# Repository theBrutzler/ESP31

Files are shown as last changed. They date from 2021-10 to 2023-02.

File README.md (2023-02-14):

# ESP31
ESP32 -> ESP01

I created a board, that could fit an ESP32 on a ESP01 standard pinout. The default ESP01 programer is still working
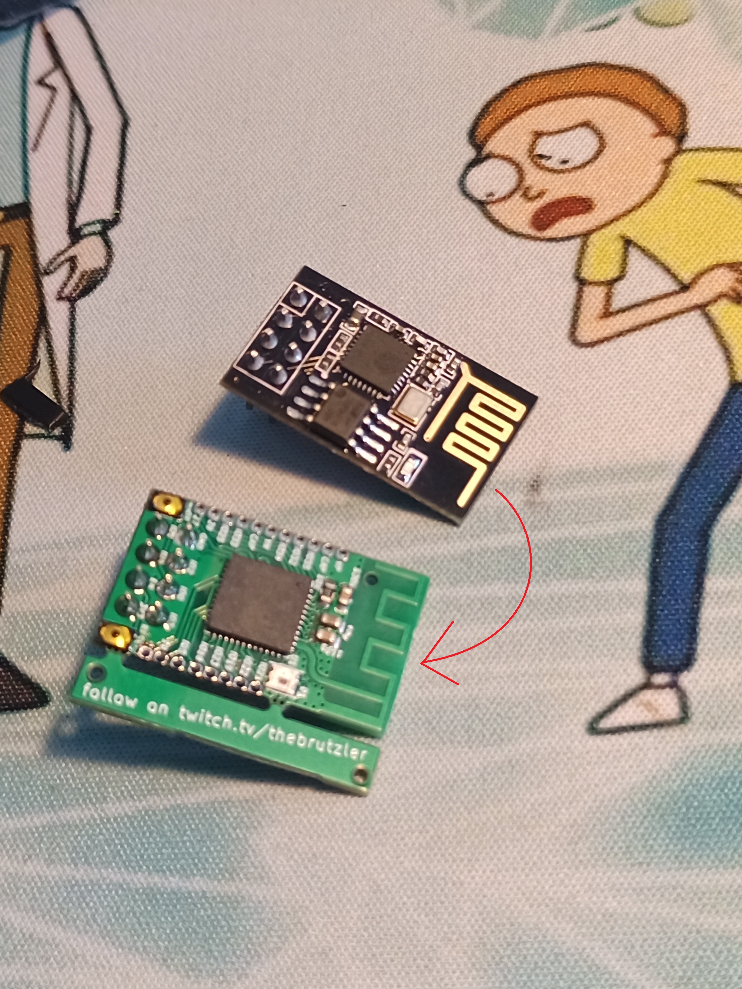
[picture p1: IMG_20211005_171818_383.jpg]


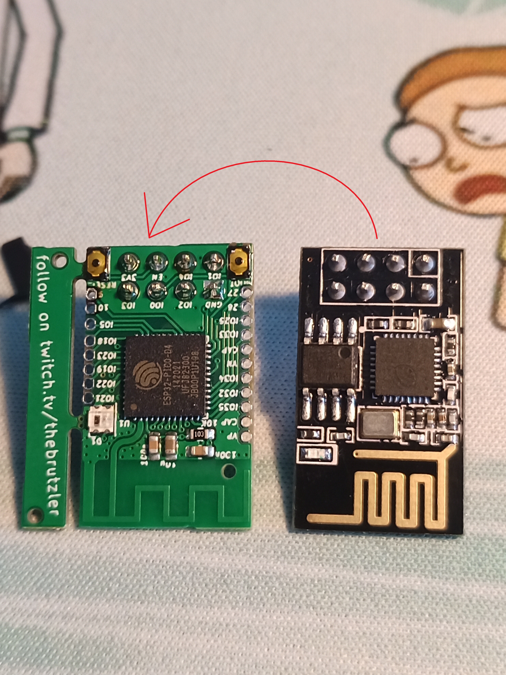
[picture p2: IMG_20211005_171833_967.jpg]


This is the NEW 5V Version but first open the RTFM.png ;)
with V4 default is 5V operation. Works fine with 3.3 too. If u have problems make the RTFM.png

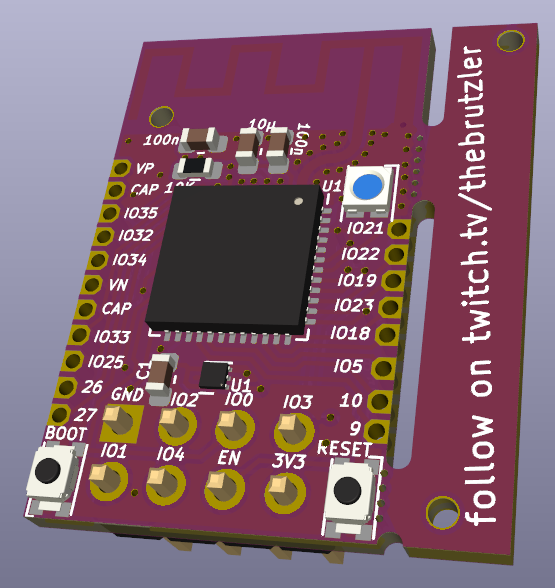
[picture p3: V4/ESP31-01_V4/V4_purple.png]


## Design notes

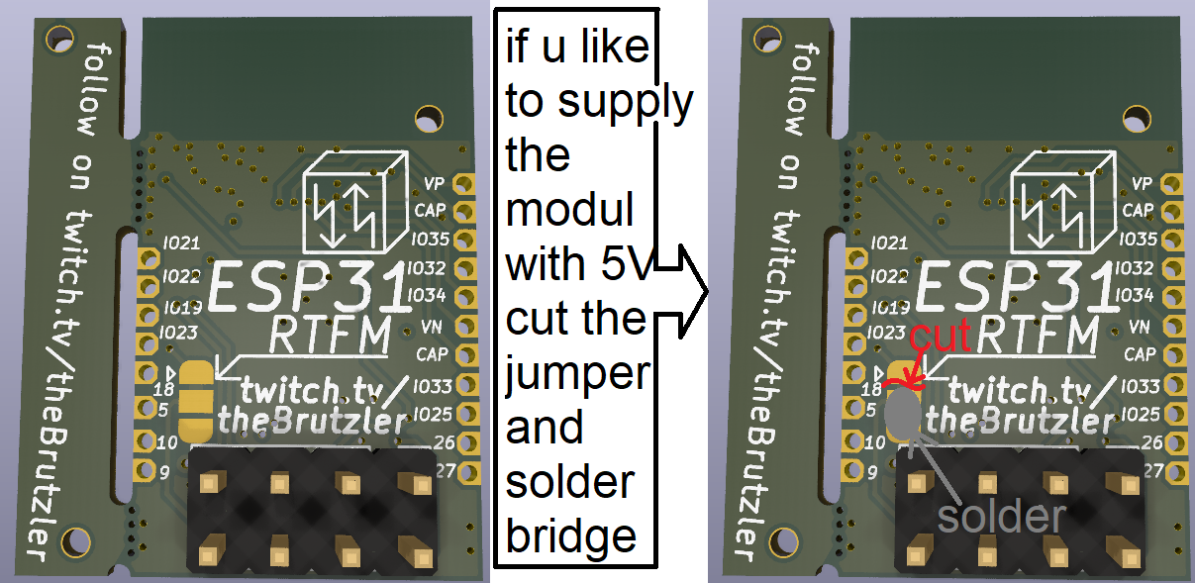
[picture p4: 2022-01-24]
RTFM.png

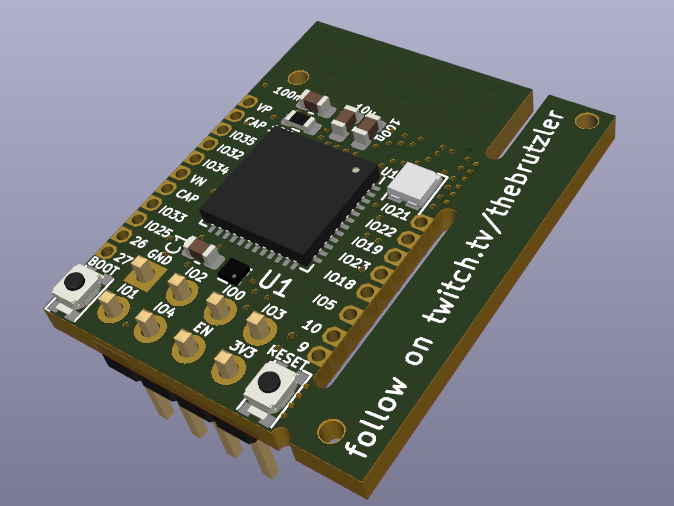
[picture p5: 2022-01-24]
V3_3D_Model.PNG

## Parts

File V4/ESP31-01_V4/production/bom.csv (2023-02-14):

Designator | Footprint | Quantity | Value | LCSC Part #
_12, _11, _10, _9, _8, _7, _6, _5, _4, _3, _2, |  | 12
AE1 | Texas_SWRA117D_2.4GHz_Left | 1 | Antenna_Shield
C1 | 0603 | 1 | 100n | C282519
C2 | 0603 | 1 | 100n | C282519
C3 | 0603 | 1 | 10µ | C85713
C4 | 0603 | 1 | 100n | C282519
D1 | LED_Cree-PLCC4_2x2mm_CW | 1 | WS2812B_Geaendertes_Symbol | C965556
J1, J10, J11, J12, J13, J14, J15, J16, J17, J18, J19, J2, J3, J4, J5, J6, J7, J8_2, J8, J9_2, J9 | CON_1x01 | 21 | Conn_01x01
J20 | PinHeader_2x04_P2.54mm_Vertical | 1 | Conn_02x04_Odd_Even
JP1, JP2 | SolderJumper-3_P1.3mm_Bridged12_RoundedPad1.0x1.5mm | 2 | SolderJumper_3_Bridged12
R1 | 0603 | 1 | 10K | C73809
SM3 | Symbol_kurzschlussblog | 1 | SYM_Arrow45_Tiny
SW1, SW2 | microswitch | 2 | SW_Push | C482003
U1 | DFN-6-1EP_1.2x1.2mm_P0.4mm_EP0.3x0.94mm_PullBack | 1 | MIC5528 | C622490
U2 | QFN-48-1EP_7x7mm_P0.5mm_EP5.3x5.3mm | 1 | ESP32-PICO-D4 | C193707

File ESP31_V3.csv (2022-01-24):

Comment | Designator | Footprint | LCSC
Antenna_Shield | AE1 | RF_Antenna:Texas_SWRA117D_2.4GHz_Left
100n | C1,C2,C4 | Capacitor_SMD:C_0603_1608Metric | C282519
10µ | C3 | Capacitor_SMD:C_0603_1608Metric | C85713
WS2812B_Geaendertes_Symbol | D1 | LED_SMD:LED_Cree-PLCC4_2x2mm_CW | C965556
Conn_01x01 | J1,J2,J3,J4,J5,J6,J7,J8,J9,J10,J11,J12,J13,J14,J15,J16,J17,J18,J19 | Eigene:CON_1x01
Conn_02x04_Odd_Even | J20 | Connector_PinHeader_2.54mm:PinHeader_2x04_P2.54mm_Vertical
SolderJumper_3_Bridged12 | JP1 | Jumper:SolderJumper-3_P1.3mm_Bridged12_RoundedPad1.0x1.5mm
10K | R1 | Resistor_SMD:R_0603_1608Metric | C73809
SW_Push | SW1,SW2 | TheBrutzlers_Lib:microswitch | C100056
WL2810 | U1 | Package_DFN_QFN:UDFN-4-1EP_1x1mm_P0.65mm_EP0.48x0.48mm | C506118
ESP32-PICO-D4 | U2 | Package_DFN_QFN:QFN-48-1EP_7x7mm_P0.5mm_EP5.3x5.3mm

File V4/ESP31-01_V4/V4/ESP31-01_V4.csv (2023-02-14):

ID | Bezeichner | Gehäuse | Stückzahl | Bezeichnung | Anbieter und Referenz
1 | J8,J5,J10,J7,J18,J9,J6,J12,J19,J13,J15,J17,J14,J8,J3,J4,J11,J9,J1,J16,J2 | CON_1x01 | 21 | Conn_01x01
2 | U1 | DFN-6-1EP_1.2x1.2mm_P0.4mm_EP0.3x0.94mm_PullBack | 1 | MIC5528
3 | C2,C1,C4 | C_0603_1608Metric | 3 | 100n
4 | REF** | jlc_tooling | 1 | jlc_tooling
5 | REF** | mousebite | 1 | mousebite
6 | ,,,,,,,,,,, |  | 12
7 | C3 | C_0603_1608Metric | 1 | 10µ
8 | U2 | QFN-48-1EP_7x7mm_P0.5mm_EP5.3x5.3mm | 1 | ESP32-PICO-D4
9 | AE1 | Texas_SWRA117D_2.4GHz_Left | 1 | Antenna_Shield
10 | R1 | R_0603_1608Metric | 1 | 10K
11 | SW1,SW2 | microswitch | 2 | SW_Push
12 | D1 | LED_Cree-PLCC4_2x2mm_CW | 1 | WS2812B_Geaendertes_Symbol
13 | JP2,JP1 | SolderJumper-3_P1.3mm_Bridged12_RoundedPad1.0x1.5mm | 2 | SolderJumper_3_Bridged12
14 | SM3 | Symbol_kurzschlussblog | 1 | SYM_Arrow45_Tiny
15 | J20 | PinHeader_2x04_P2.54mm_Vertical | 1 | Conn_02x04_Odd_Even

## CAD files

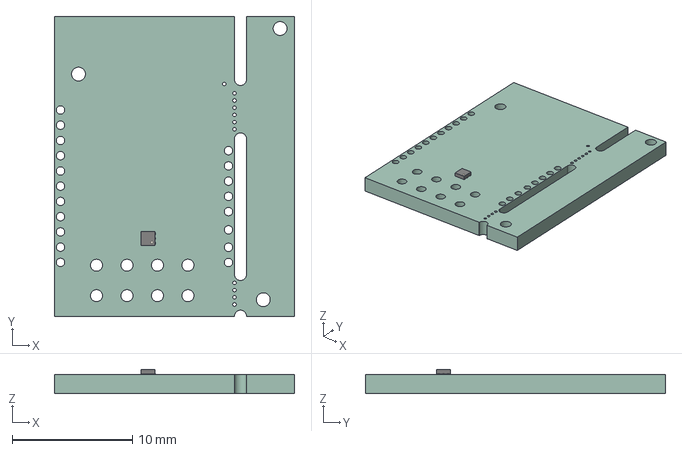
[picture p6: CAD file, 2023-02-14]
V4/ESP31-01_V4/ESP31-01_V4.step
20.0 x 25.0 x 2.04 mm
ESP31_V3 PCB

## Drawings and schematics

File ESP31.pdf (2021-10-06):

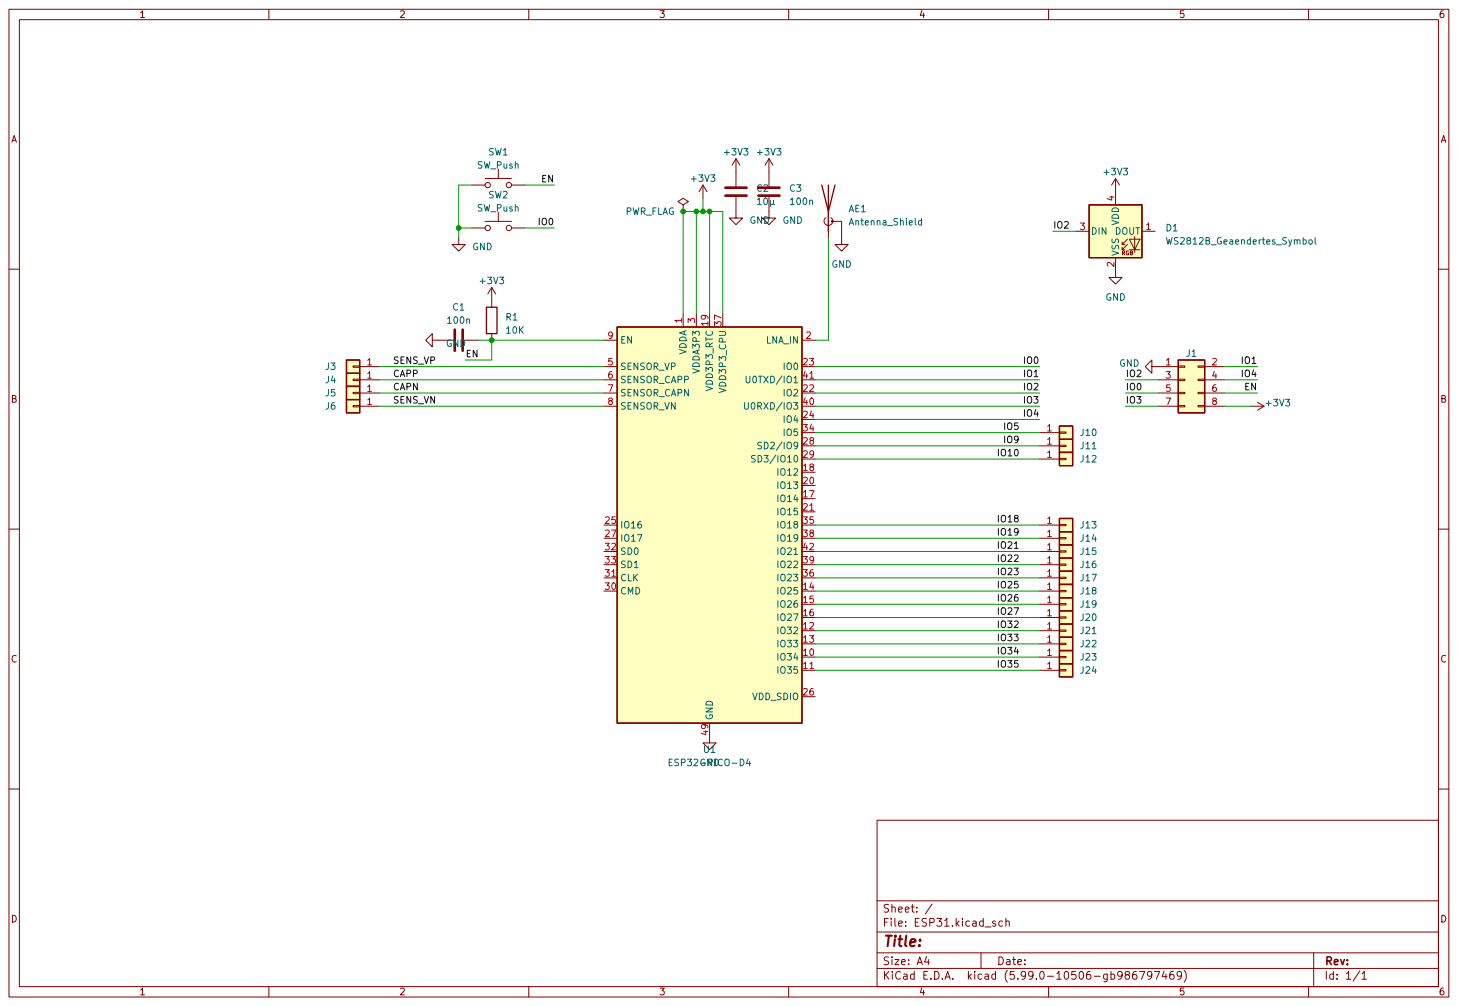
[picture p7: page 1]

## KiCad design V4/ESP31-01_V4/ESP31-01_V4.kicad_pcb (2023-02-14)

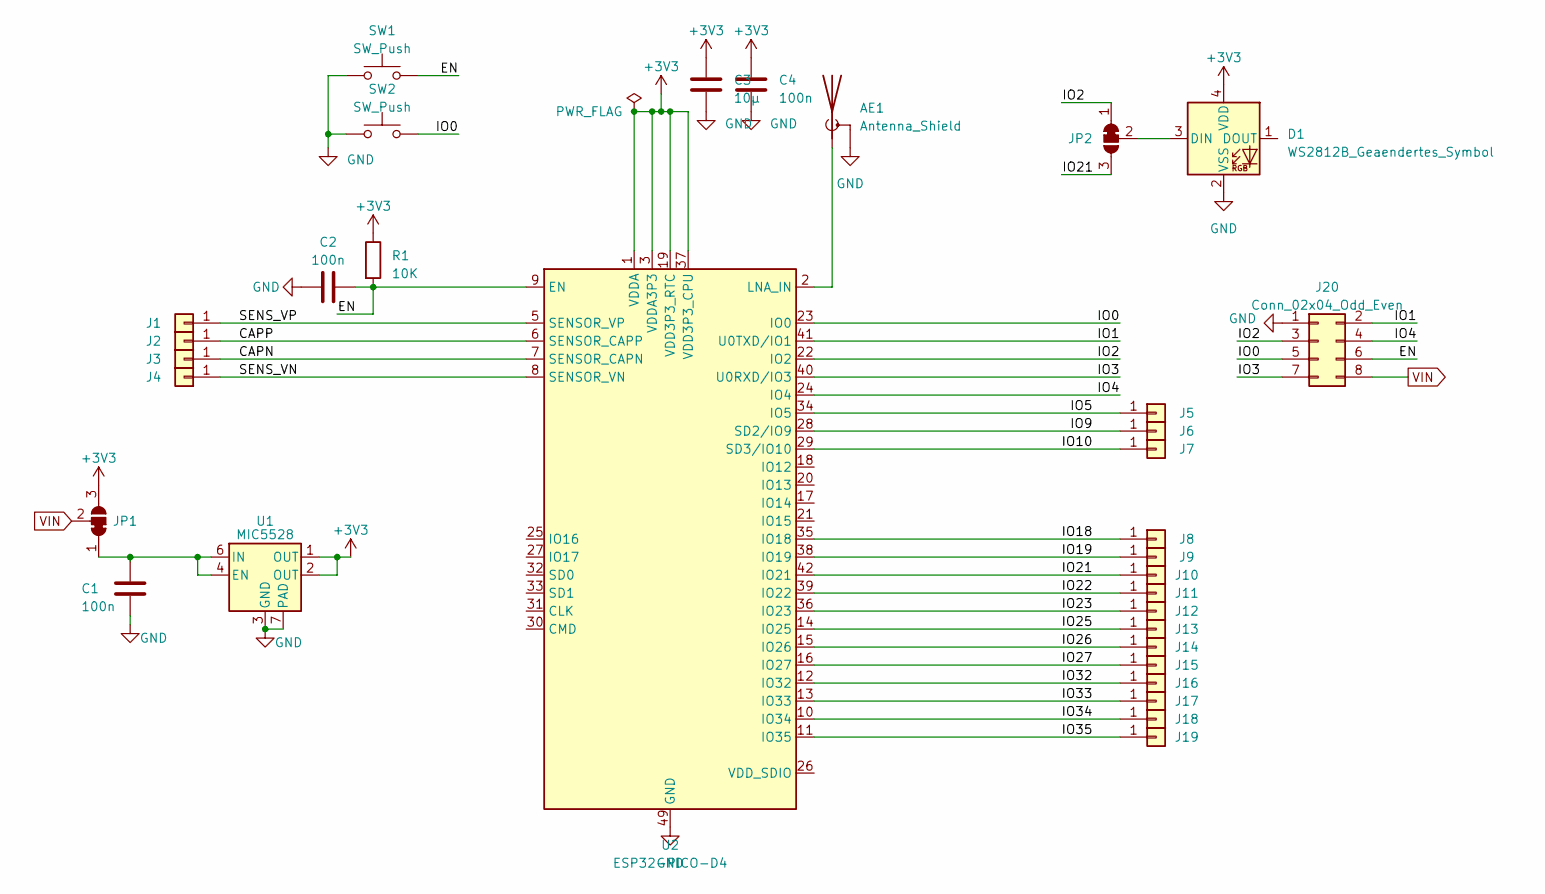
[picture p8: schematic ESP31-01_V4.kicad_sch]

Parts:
AE1: Antenna_Shield; Texas_SWRA117D_2.4GHz_Left
C1, C2, C4: 100n; C_0603_1608Metric; LCSC C282519
C3: 10µ; C_0603_1608Metric; LCSC C85713
D1: WS2812B_Geaendertes_Symbol; LED_Cree-PLCC4_2x2mm_CW; LCSC C965556
J1, J2, J3, J4, J5, J6, J7, J8, J9, J10, J11, J12, J13, J14, J15, J16, J17, J18, J19: Conn_01x01; CON_1x01
J20: Conn_02x04_Odd_Even; PinHeader_2x04_P2.54mm_Vertical
JP1, JP2: SolderJumper_3_Bridged12; SolderJumper-3_P1.3mm_Bridged12_RoundedPad1.0x1.5mm
R1: 10K; R_0603_1608Metric; LCSC C73809
SW1: SW_Push; microswitch; LCSC C482003
SW2: SW_Push; microswitch; LCSC C100056
U1: MIC5528; DFN-6-1EP_1.2x1.2mm_P0.4mm_EP0.3x0.94mm_PullBack; LCSC C622490
U2: ESP32-PICO-D4; QFN-48-1EP_7x7mm_P0.5mm_EP5.3x5.3mm; LCSC C193707

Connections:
+3V3: C3.2, C4.2, D1.4 (VDD), JP1.3 (B), R1.1, U1.1 (OUT), U1.2 (OUT), U2.1 (VDDA), U2.3 (VDDA3P3), U2.4 (VDDA3P3), U2.19 (VDD3P3_RTC), U2.37 (VDD3P3_CPU), U2.43 (VDDA), U2.46 (VDDA)
/CAPN: J3.1, U2.7 (SENSOR_CAPN)
/CAPP: J2.1, U2.6 (SENSOR_CAPP)
/EN: C2.1, J20.6, R1.2, SW1.2, U2.9 (EN)
/IO0: J20.5, SW2.2, U2.23 (IO0)
/IO1: J20.2, U2.41 (U0TXD/IO1)
/IO2: J20.3, JP2.1 (A), U2.22 (IO2)
/IO3: J20.7, U2.40 (U0RXD/IO3)
/IO4: J20.4, U2.24 (IO4)
/IO5: J5.1, U2.34 (IO5)
/IO9: J6.1, U2.28 (SD2/IO9)
/IO10: J7.1, U2.29 (SD3/IO10)
/IO18: J8.1, U2.35 (IO18); also elsewhere on the board
/IO19: J9.1, U2.38 (IO19)
/IO21: J10.1, JP2.3 (B), U2.42 (IO21)
/IO22: J11.1, U2.39 (IO22)
/IO23: J12.1, U2.36 (IO23)
/IO25: J13.1, U2.14 (IO25)
/IO26: J14.1, U2.15 (IO26)
/IO27: J15.1, U2.16 (IO27)
/IO32: J16.1, U2.12 (IO32)
/IO33: J17.1, U2.13 (IO33)
/IO34: J18.1, U2.10 (IO34)
/IO35: J19.1, U2.11 (IO35)
/SENS_VN: J4.1, U2.8 (SENSOR_VN)
/SENS_VP: J1.1, U2.5 (SENSOR_VP)
GND: AE1.2 (Shield), C1.1, C2.2, C3.1, C4.1, D1.2 (VSS), J20.1, SW1.1, SW2.1, U1.3 (GND), U1.7 (PAD), U2.49 (GND)
unnamed: AE1.1 (A), U2.2 (LNA_IN)
unnamed: C1.2, JP1.1 (A), U1.4 (EN), U1.6 (IN)
unnamed: D1.3 (DIN), JP2.2 (C)
VIN: J20.8, JP1.2 (C)

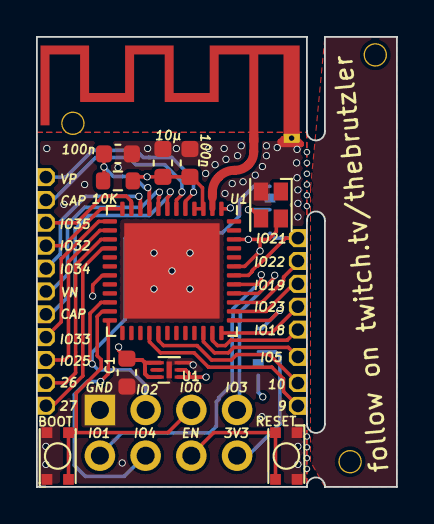
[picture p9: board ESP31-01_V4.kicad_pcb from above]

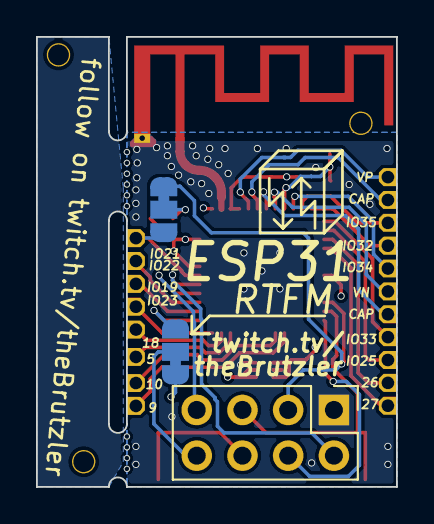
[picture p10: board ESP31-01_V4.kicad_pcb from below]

Board: 4 copper layers, 20.0 x 25.0 mm, 36 parts (4 on the bottom side), 31 nets.

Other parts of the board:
J8#2, J9#2: Conn_01x01; CON_1x01
SM3: SYM_Arrow45_Tiny; Symbol_kurzschlussblog

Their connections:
/IO18: J8#2.1; also elsewhere on the board

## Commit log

2021-08-17 initial upload
    [ESP31.kicad_pcb, ESP31.kicad_sch]
2021-10-04 Final Version
    Last ordered version. It's working :)
    [BOM_JLCSMT.xlsx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]
2021-10-07 corrected WS2812 Footprint
    On V1 the WS2812 was not working, because of a Footprint issue. #1
    [BOM_JLCSMT.xlsx, ESP31.csv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]
2021-10-07 Upload xlsx JLCPCB
    [BOM_JLCSMT.xlsx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]
2021-10-07 update html bom
2022-02-03 corrected WS2812 Footprint
    corrected WS2812 Footprint
    switched input and output of RGB LED
    [ESP31_V3-B_Cu.gbr, ESP31_V3-B_Mask.gbr, ESP31_V3-B_Silkscreen.gbr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]
2022-02-03 corrected WS2812 Footprint
    [ESP31_V3-B_Cu.gbr, ESP31_V3-B_Cu_.gbr, ESP31_V3-B_Mask.gbr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]
2023-02-14 Update to V4
    Updatet LDO to better solderable footprint
    [ESP31-01_V4-B_Cu.gbr, ESP31-01_V4-B_Mask.gbr, ESP31-01_V4-B_Silkscreen.gbr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]
